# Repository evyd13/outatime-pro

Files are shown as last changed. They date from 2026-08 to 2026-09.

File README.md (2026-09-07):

# Outatime Pro
A PCB for Casio CA-53W or 3208 module based on the [Sensor Watch Pro](https://github.com/joeycastillo/Sensor-Watch). It has the same features!

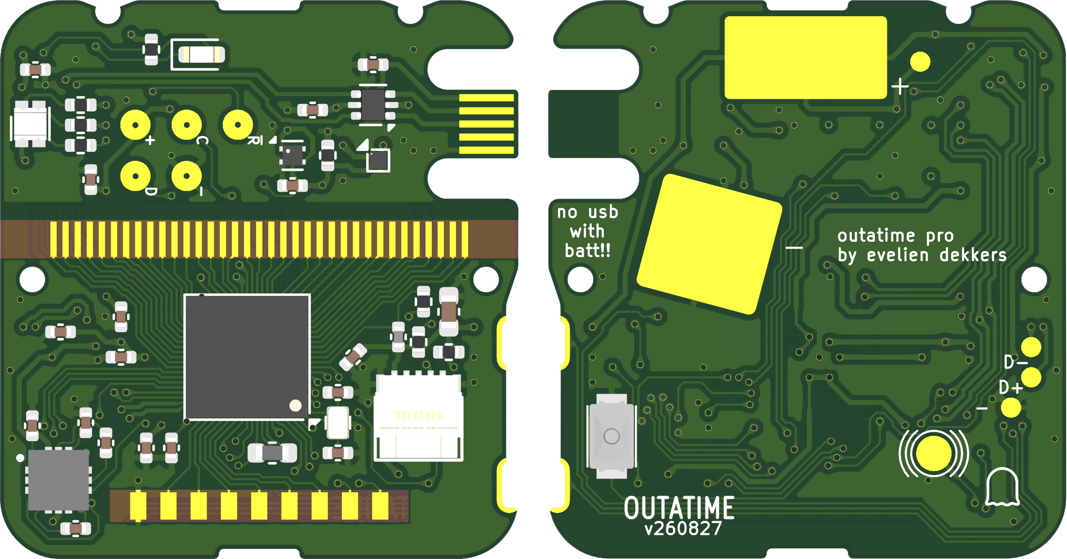
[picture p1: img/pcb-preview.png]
PCB view


# Firmware
Firmware is being worked on [here](https://github.com/evyd13/second-movement/tree/outatime-pro).

# WARNING
THIS IS NOT TESTED IN ANY WAY. DO NOT ORDER THIS THINKING IT WILL WORK. FIRMWARE DOESN'T EXIST FOR IT YET. IT IS A WORK IN PROGRESS.
However, the PCB design is done.

## Version number
Version number is date formate yyMMDD, August 25th 2026 would be v260825.

# To-Do
The following still needs work:

- Firmware needs to be finished (work has started!)
- figure out if the selection signals for PAM8904 need to be connected to GPIO or always HIGH.
- PCB needs to be ordered and tested (I intend to do this in a few months time, need to gather funds for a prototype)
- It needs to be worn and loved!!

# Bootloader
I contacted devolov, they said to me that the firmware needs to be flashed with utils/flash_watch_pyruler using Adafruit PyRuler or Trinket. (I intend to use Seeed XIAO or maybe Pi Pico.)

Bootloader.h is generated from https://github.com/joeycastillo/uf2-samdx1.
(Thanks @devolov!)

# LCD
The LCD is fairly simple. It has 35 pins, of which the leftmost is not connected. The first 3 connected pins are common, the rest are segments. Mapping can be found within the emulator svg file or watch_common_display.h. (Seg08 and seg01 are swapped in software to allow blinking)

# Thanks to and relevant projects
- Joey Castillo for Sensor Watch, which this project is mostly based on. https://github.com/joeycastillo/Sensor-Watch/tree/main
- Travis Goodspeed, for incredible documentation about the Casio CA-53W. https://github.com/travisgoodspeed/goodwatch
- Vasily Zhuravsky, for a nice USB edge connector library https://github.com/vasya-zh/PCB-Edge-USB-connector-KiCad-library
- Dmitry Teplitsky, for making me think I can do it https://github.com/icelord75/icesio
- Greg Davill, for pointing the way to a microcontroller to use. https://github.com/gregdavill/advent-calendar-of-circuits-2020/tree/main/arm-watch

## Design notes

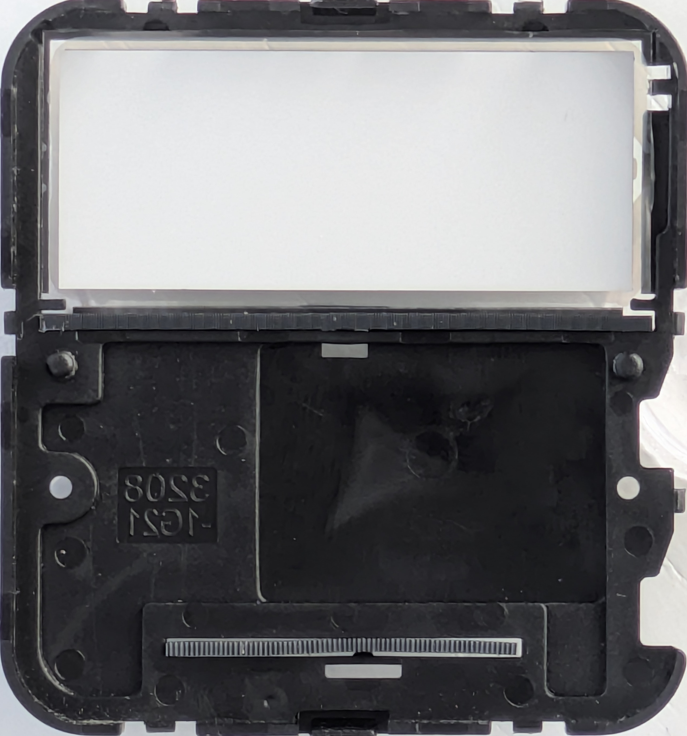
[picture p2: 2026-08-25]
PCB/ref/display cover.png

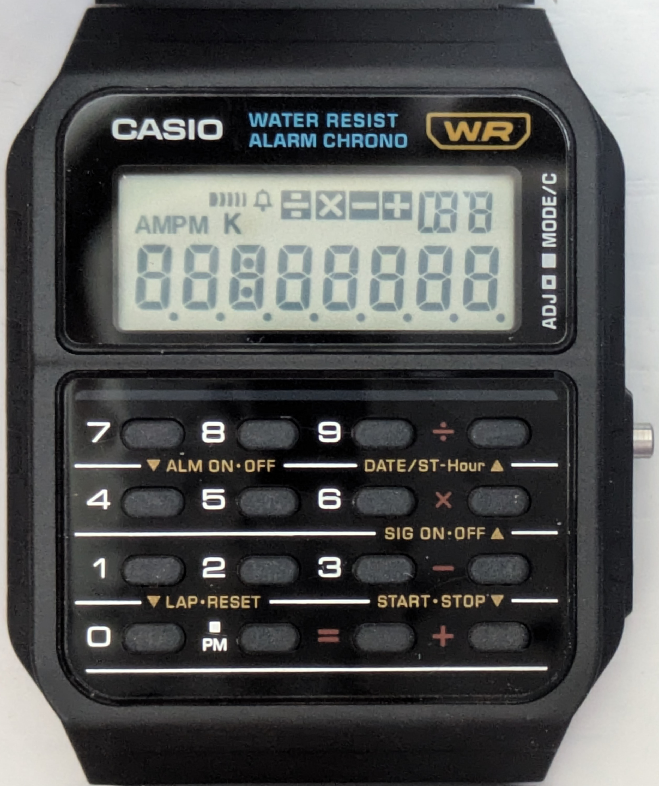
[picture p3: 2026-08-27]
PCB/ref/display.png

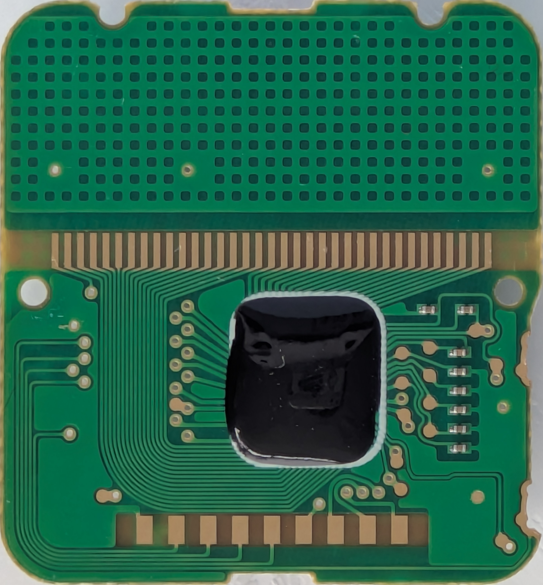
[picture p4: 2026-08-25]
PCB/ref/display side.png

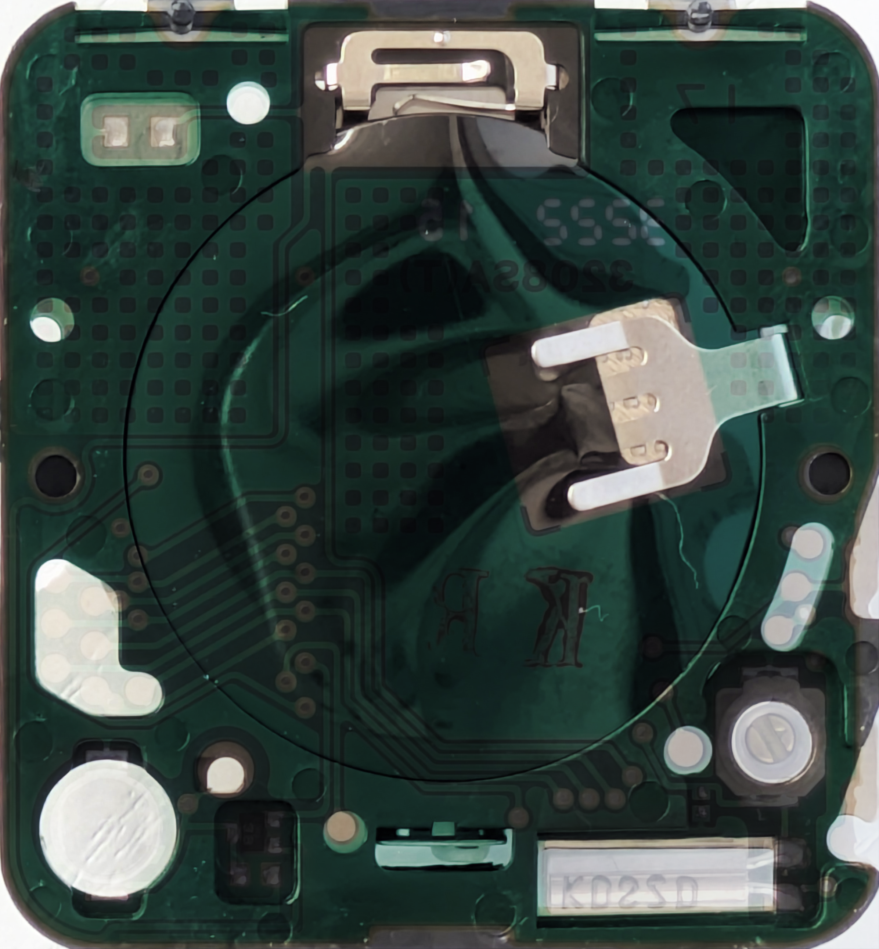
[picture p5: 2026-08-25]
PCB/ref/battery side w battery cover.png

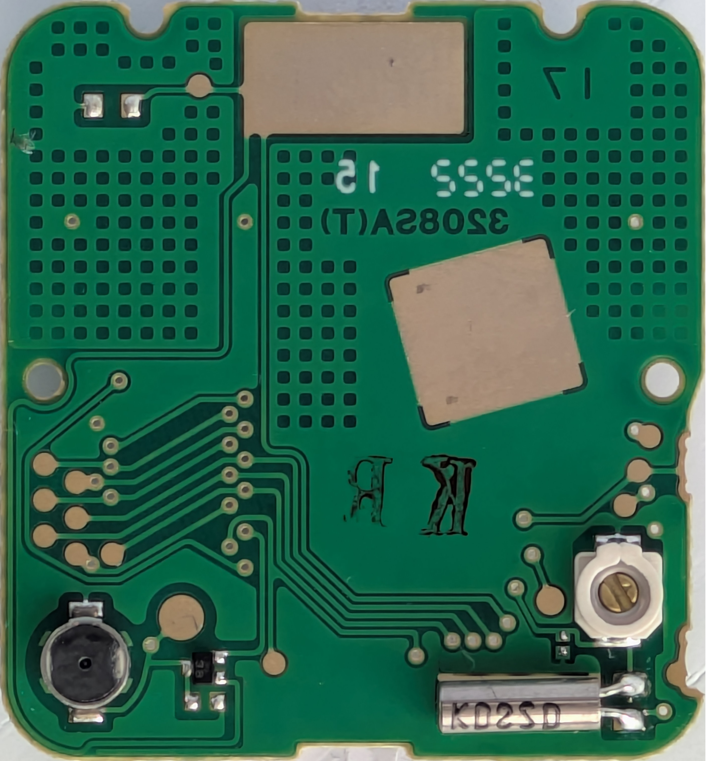
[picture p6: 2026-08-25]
PCB/ref/battery side.png

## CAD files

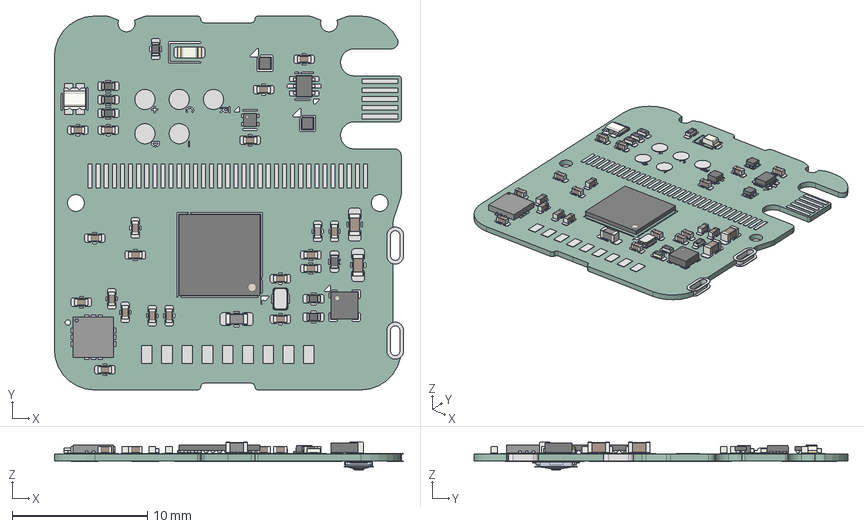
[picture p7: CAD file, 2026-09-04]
PCB/OutatimePro.step
25.9 x 27.7 x 2.04 mm
C_0402_1005Metric x 19
LED_0603_1608Metric v1
FC1610AN_PKG
UFBGA-100_6.0x6.0mm_Layout11x11_P0.5mm_Ball0.3mm_Pad0.25mm_NSMD v1
R_0402_1005Metric x 7
TH_0402_1005Metric v1
C_0603_1608Metric x 2
LGA-12_2x2mm_P0.5mm v1
WLP-4_0.83x0.83mm_P0.4mm x 2
SOT_666
PAM8904JPR v1
DFN_4_1EP_1x1mm_P065mm_EP05x05mm
L_0603_1608Metric
3Dmodel
OutatimePro_pad
OutatimePro_silkscreen x 2
OutatimePro_PCB

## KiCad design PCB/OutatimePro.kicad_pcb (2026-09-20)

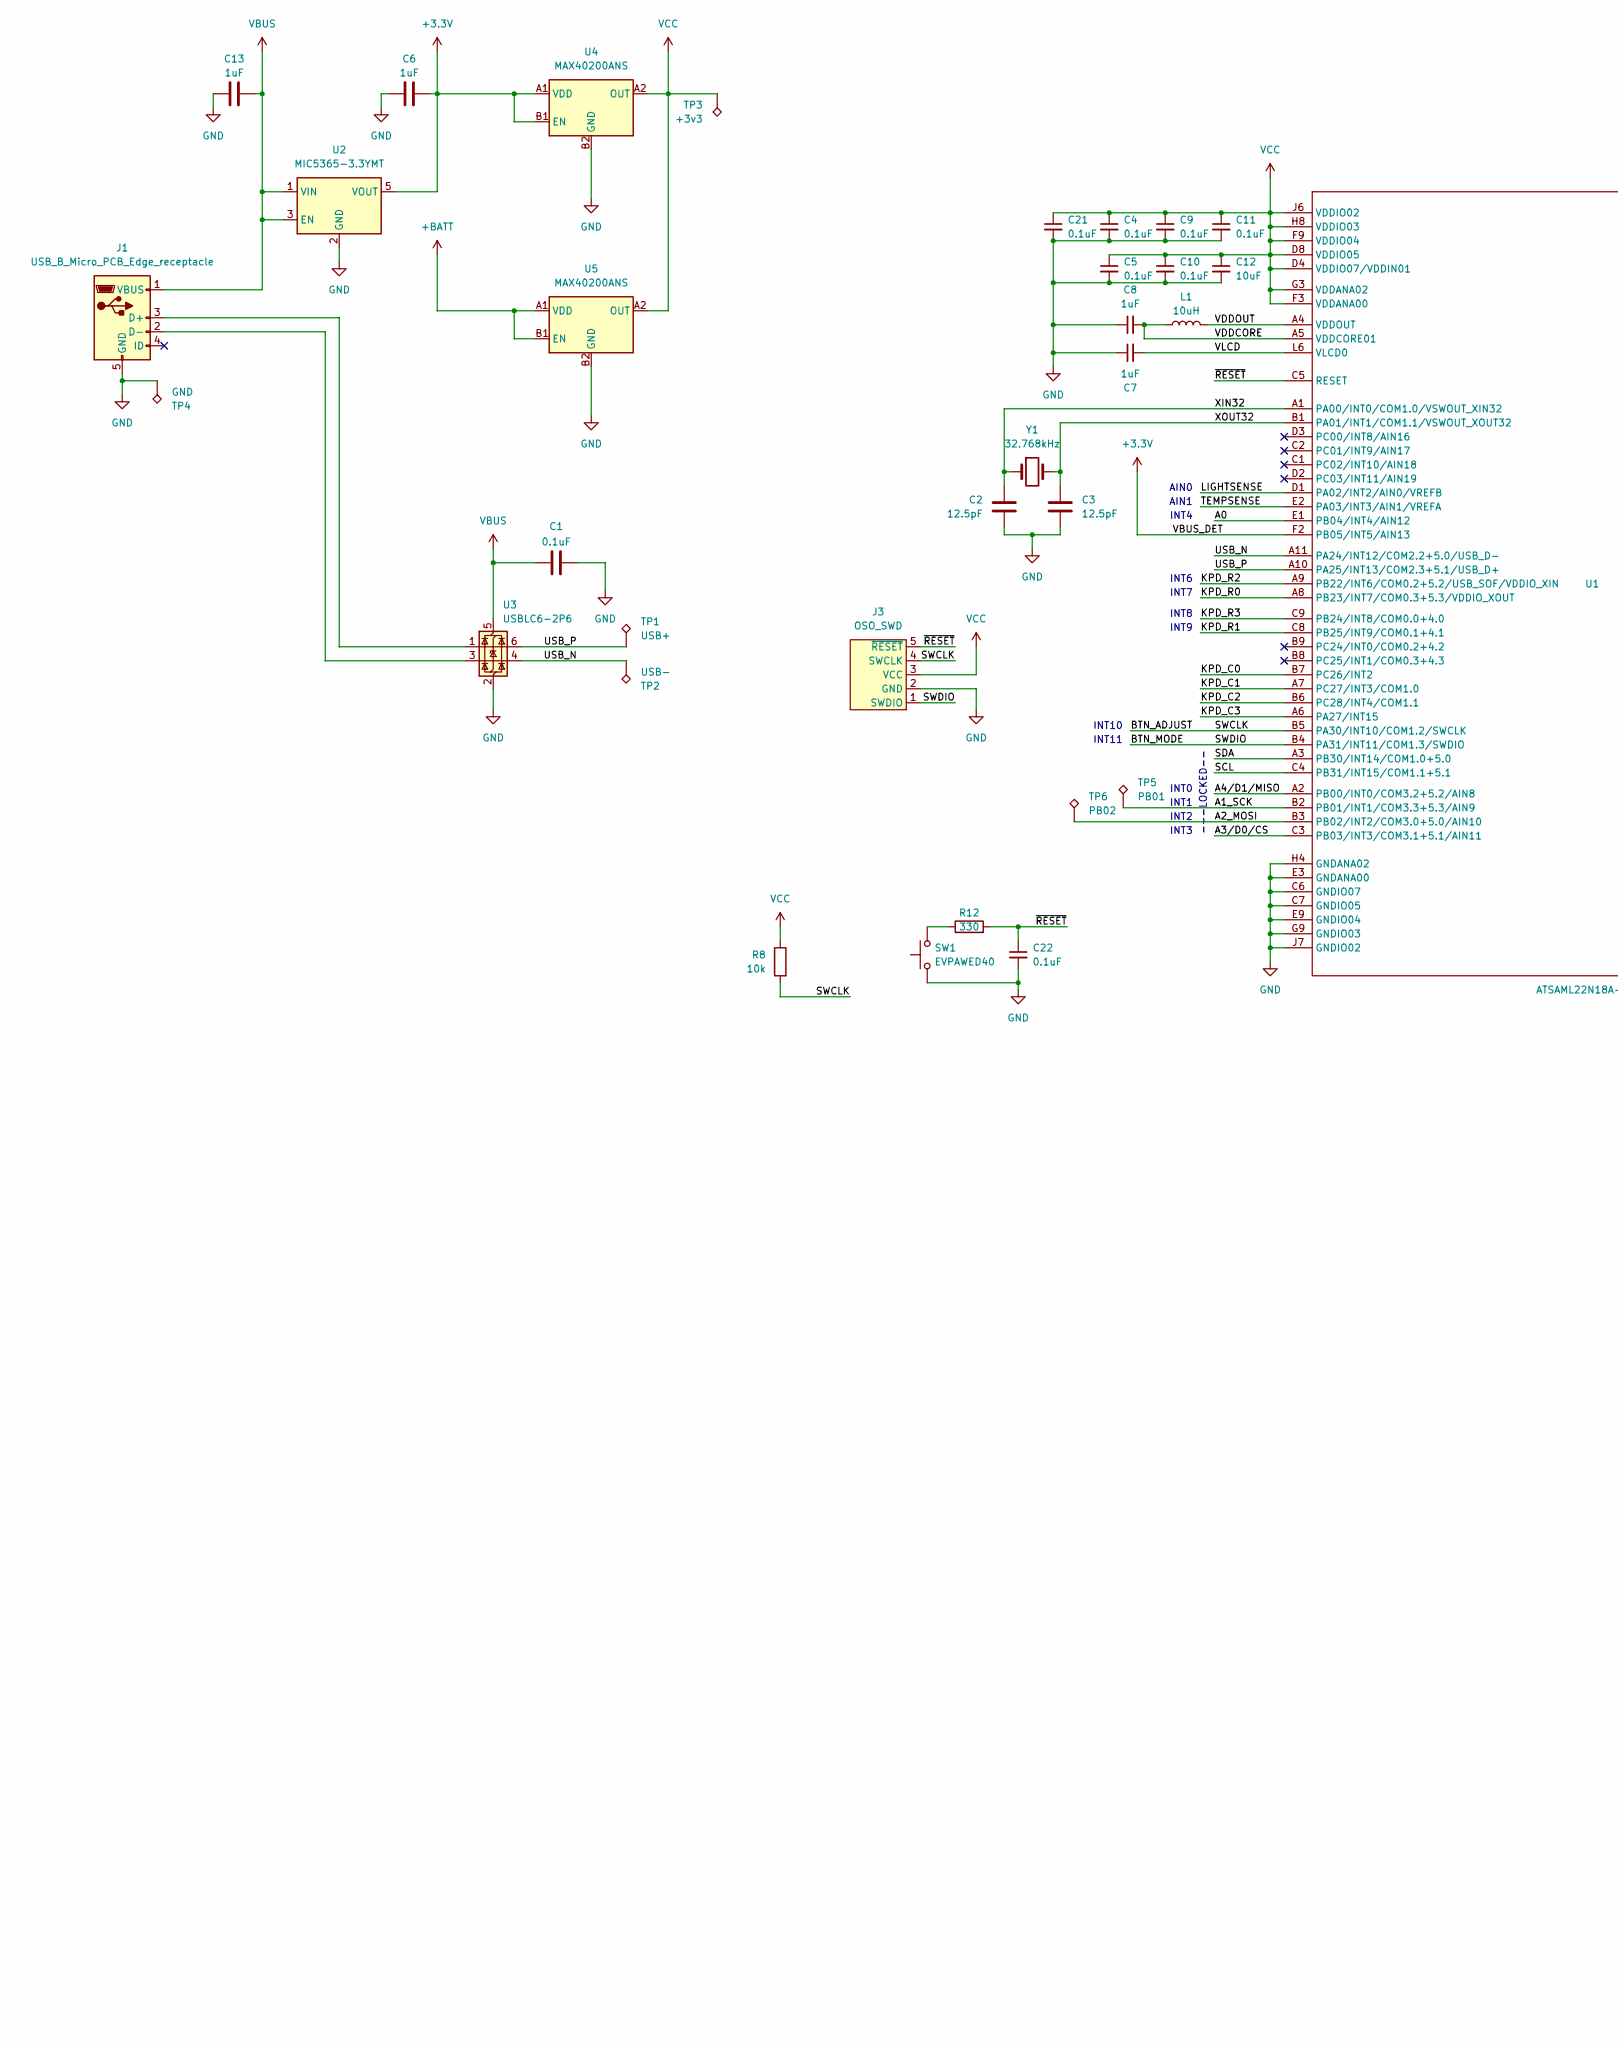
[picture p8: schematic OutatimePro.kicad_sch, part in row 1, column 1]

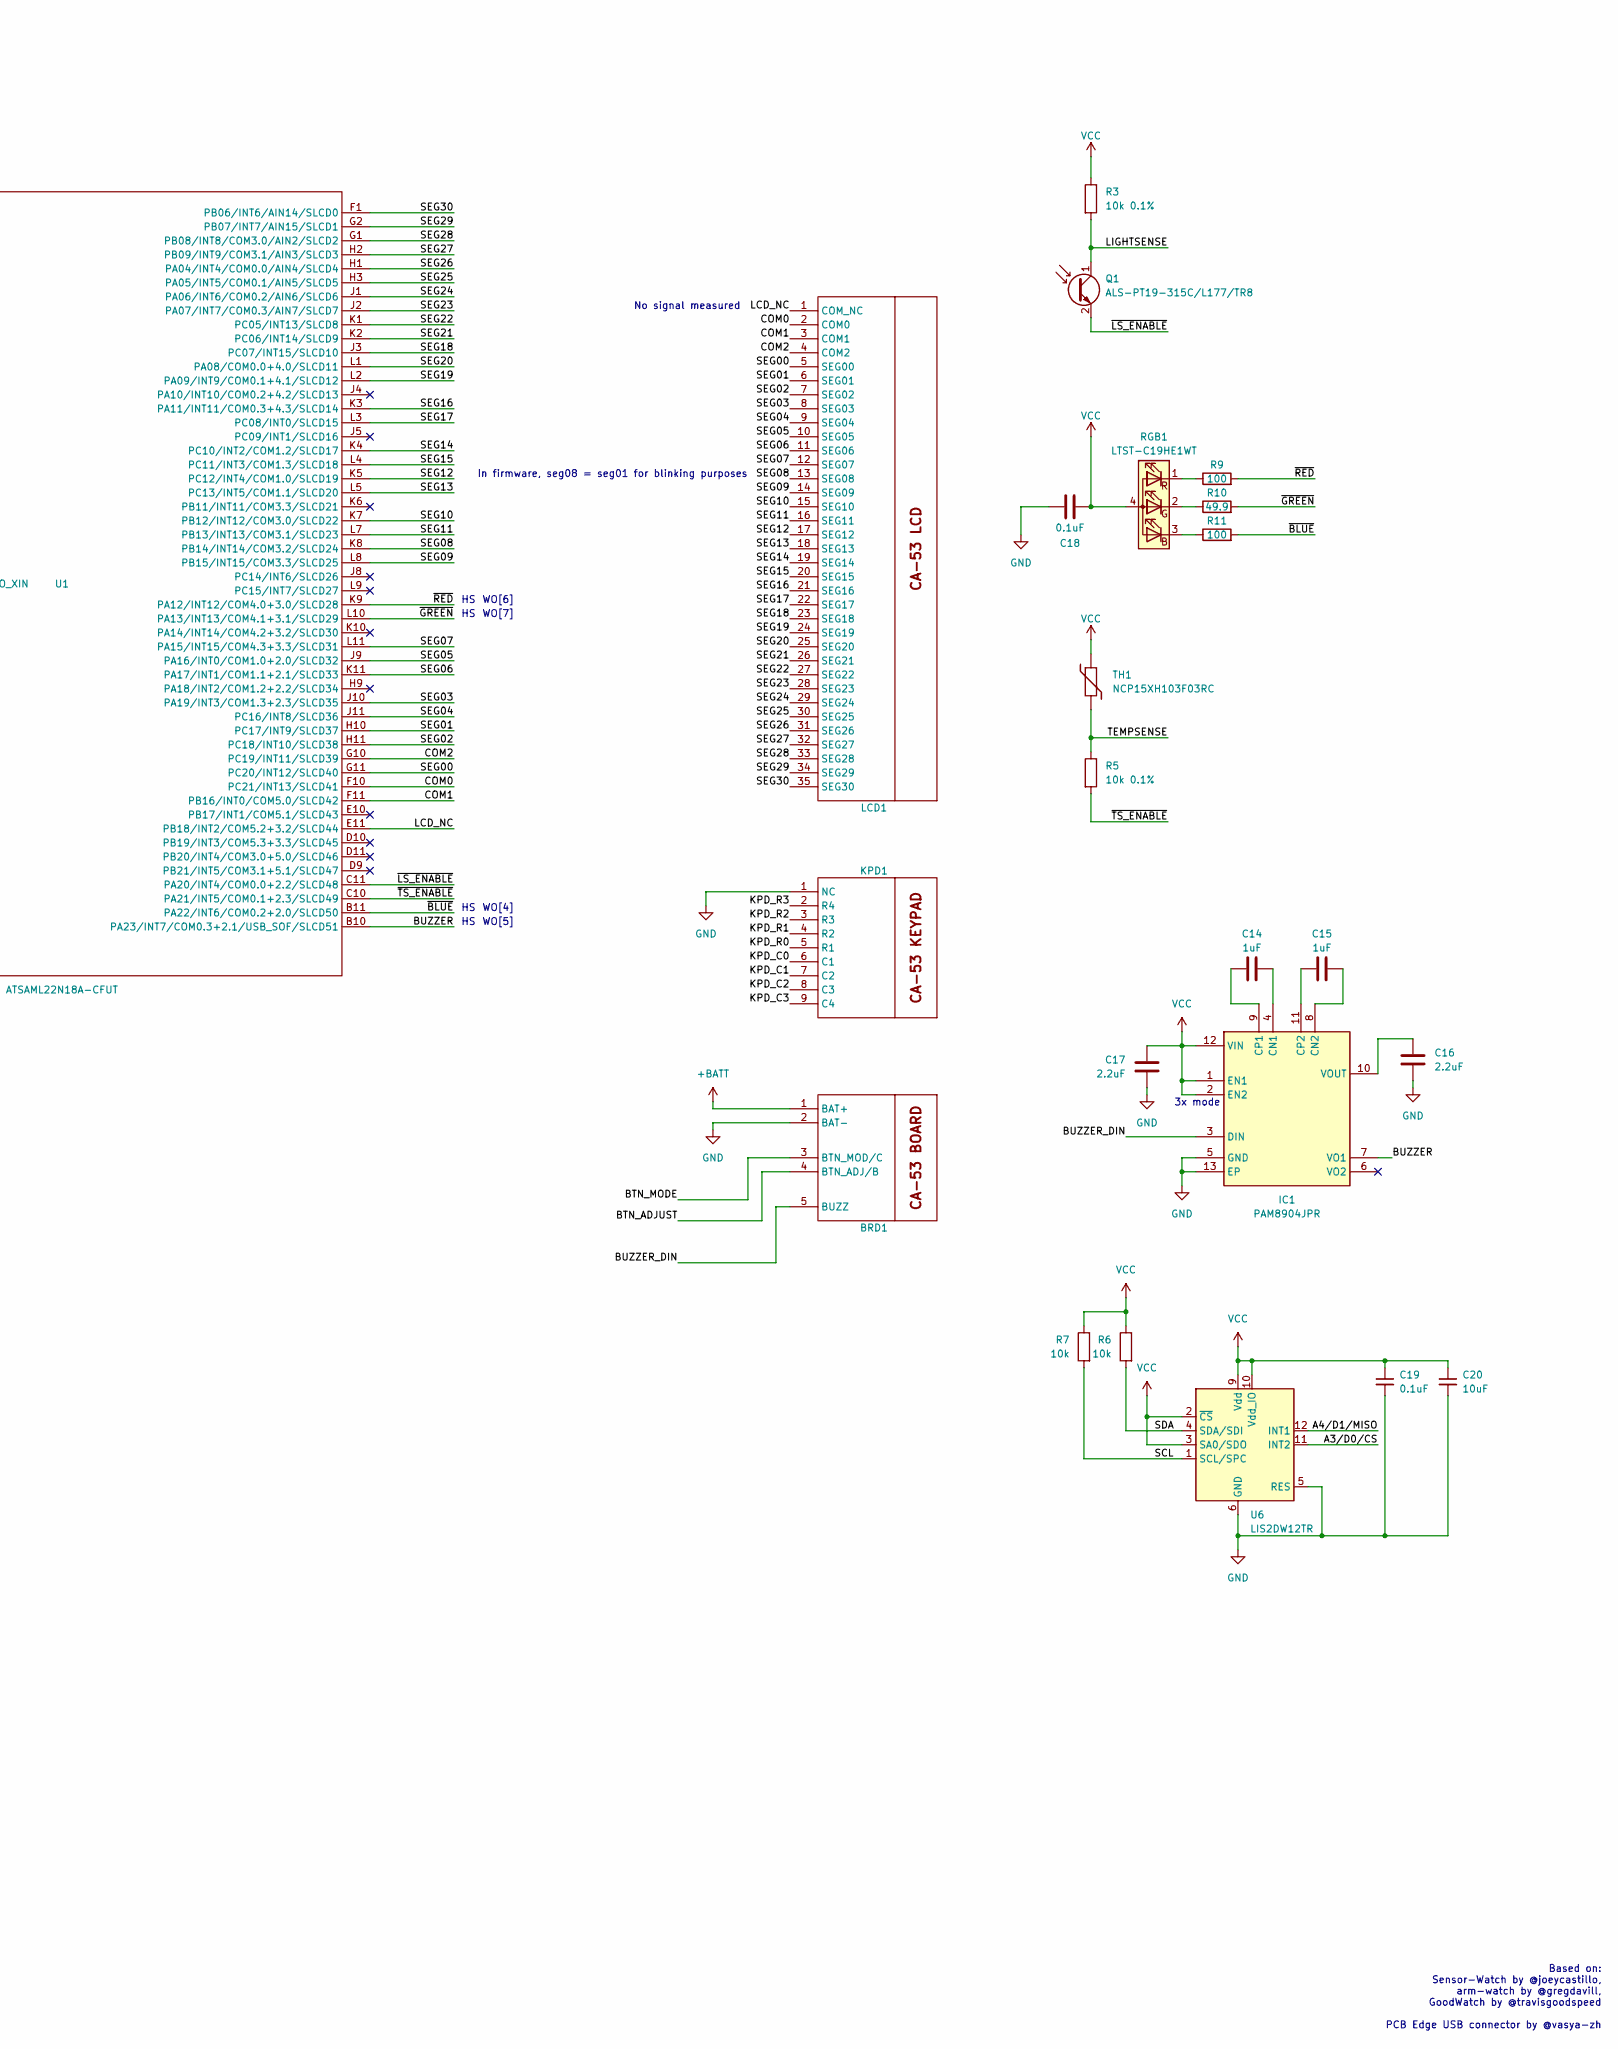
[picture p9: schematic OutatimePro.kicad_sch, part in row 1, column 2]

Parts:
BRD1: ca53board
C1, C4, C5, C9, C10, C11, C18, C19, C21, C22: 0.1uF; C_0402_1005Metric; LCSC Part # C14663
C2, C3: 12.5pF; C_0402_1005Metric; LCSC Part # C1547
C6, C7, C8, C13, C14, C15: 1uF; C_0402_1005Metric; LCSC Part # C52923
C12, C20: 10uF; C_0603_1608Metric; LCSC Part # C19702
C16, C17: 2.2uF; C_0402_1005Metric; LCSC Part # C12530
IC1: PAM8904JPR; LCSC Part # C780875
J1: USB_B_Micro_PCB_Edge_receptacle; USB_Micro-B_PCB_receptacle_5pin_2mm_cutout
J3: OSO_SWD; OSO_SWD_2x3
KPD1: ca53keypad
L1: 10uH; L_0603_1608Metric; LCSC Part # C1035
LCD1: ca53lcd
Q1: ALS-PT19-315C/L177/TR8; ALS-PT19-315C; LCSC Part # C146233
R3, R5: 10k 0.1%; R_0402_1005Metric; LCSC Part # C517449
R6, R7, R8: 10k; R_0402_1005Metric; LCSC Part # C25744
R9, R11: 100; R_0402_1005Metric; LCSC Part # C25076
R10: 49.9; R_0402_1005Metric; LCSC Part # C25120
R12: 330; R_0402_1005Metric; LCSC Part # C25104
RGB1: LTST-C19HE1WT; LED_LiteOn_LTST-C19HE1WT; LCSC Part # C458749
SW1: EVPAWED40; Panasonic_EVPAW_EVP6A; LCSC Part # C2858607
TH1: NCP15XH103F03RC; TH_0402_1005Metric; LCSC Part # C77131
TP1: USB+; TestPoint_Pad_D1.0mm
TP2: USB-; TestPoint_Pad_D1.0mm
TP3: +3v3; TestPoint_Pad_D1.0mm
TP4: GND; TestPoint_Pad_D1.0mm
TP5: PB01; TestPoint_Pad_D1.0mm
TP6: PB02; TestPoint_Pad_D1.0mm
U1: ATSAML22N18A-CFUT; UFBGA-100_6.0x6.0mm_Layout11x11_P0.5mm_Ball0.3mm_Pad0.25mm_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; LCSC Part # C2055605
U2: MIC5365-3.3YMT; UDFN-4-1EP_1x1mm_P0.65mm_EP0.48x0.48mm; LCSC Part # C512103
U3: USBLC6-2P6; SOT-666; LCSC Part # C15999
U4, U5: MAX40200ANS; WLP-4_0.728x0.728mm_Layout2x2_P0.35mm; LCSC Part # C3227637
U6: LIS2DW12TR; LGA-12_2x2mm_P0.5mm; LCSC Part # C189624
Y1: 32.768kHz; Crystal_SMD_1610-2Pin_1.6x1.0mm; LCSC Part # C5154201

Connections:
+3.3V: C6.2, U1.F2 (PB05/INT5/AIN13), U2.5 (VOUT), U4.A1 (VDD), U4.B1 (EN)
+BATT: BRD1.1 (BAT+), U5.A1 (VDD), U5.B1 (EN)
/A0: U1.E1 (PB04/INT4/AIN12)
/A1_SCK: TP5.1 (1_1), U1.B2 (PB01/INT1/COM3.3+5.3/AIN9)
/A2_MOSI: TP6.1 (1_1), U1.B3 (PB02/INT2/COM3.0+5.0/AIN10)
/A3/D0/CS: U1.C3 (PB03/INT3/COM3.1+5.1/AIN11), U6.11 (INT2)
/A4/D1/MISO: U1.A2 (PB00/INT0/COM3.2+5.2/AIN8), U6.12 (INT1)
/BTN_ADJUST: BRD1.4 (BTN_ADJ/B), J3.4 (SWCLK), R8.2, U1.B5 (PA30/INT10/COM1.2/SWCLK)
/BTN_MODE: BRD1.3 (BTN_MOD/C), J3.1 (SWDIO), U1.B4 (PA31/INT11/COM1.3/SWDIO)
/BUZZER: IC1.7 (VO1), U1.B10 (PA23/INT7/COM0.3+2.1/USB_SOF/SLCD51)
/BUZZER_DIN: BRD1.5 (BUZZ), IC1.3 (DIN)
/COM0: LCD1.2 (COM0), U1.F10 (PC21/INT13/SLCD41)
/COM1: LCD1.3 (COM1), U1.F11 (PB16/INT0/COM5.0/SLCD42)
/COM2: LCD1.4 (COM2), U1.G10 (PC19/INT11/SLCD39)
/KPD_C0: KPD1.6 (C1), U1.B7 (PC26/INT2)
/KPD_C1: KPD1.7 (C2), U1.A7 (PC27/INT3/COM1.0)
/KPD_C2: KPD1.8 (C3), U1.B6 (PC28/INT4/COM1.1)
/KPD_C3: KPD1.9 (C4), U1.A6 (PA27/INT15)
/KPD_R0: KPD1.5 (R1), U1.A8 (PB23/INT7/COM0.3+5.3/VDDIO_XOUT)
/KPD_R1: KPD1.4 (R2), U1.C8 (PB25/INT9/COM0.1+4.1)
/KPD_R2: KPD1.3 (R3), U1.A9 (PB22/INT6/COM0.2+5.2/USB_SOF/VDDIO_XIN)
/KPD_R3: KPD1.2 (R4), U1.C9 (PB24/INT8/COM0.0+4.0)
/LCD_NC: LCD1.1 (COM_NC), U1.E11 (PB18/INT2/COM5.2+3.2/SLCD44)
/LIGHTSENSE: Q1.1 (C), R3.2, U1.D1 (PA02/INT2/AIN0/VREFB)
/SCL: R7.2, U1.C4 (PB31/INT15/COM1.1+5.1), U6.1 (SCL/SPC)
/SDA: R6.2, U1.A3 (PB30/INT14/COM1.0+5.0), U6.4 (SDA/SDI)
/SEG00: LCD1.5 (SEG00), U1.G11 (PC20/INT12/SLCD40)
/SEG01: LCD1.6 (SEG01), U1.H10 (PC17/INT9/SLCD37)
/SEG02: LCD1.7 (SEG02), U1.H11 (PC18/INT10/SLCD38)
/SEG03: LCD1.8 (SEG03), U1.J10 (PA19/INT3/COM1.3+2.3/SLCD35)
/SEG04: LCD1.9 (SEG04), U1.J11 (PC16/INT8/SLCD36)
/SEG05: LCD1.10 (SEG05), U1.J9 (PA16/INT0/COM1.0+2.0/SLCD32)
/SEG06: LCD1.11 (SEG06), U1.K11 (PA17/INT1/COM1.1+2.1/SLCD33)
/SEG07: LCD1.12 (SEG07), U1.L11 (PA15/INT15/COM4.3+3.3/SLCD31)
/SEG08: LCD1.13 (SEG08), U1.K8 (PB14/INT14/COM3.2/SLCD24)
/SEG09: LCD1.14 (SEG09), U1.L8 (PB15/INT15/COM3.3/SLCD25)
/SEG10: LCD1.15 (SEG10), U1.K7 (PB12/INT12/COM3.0/SLCD22)
/SEG11: LCD1.16 (SEG11), U1.L7 (PB13/INT13/COM3.1/SLCD23)
/SEG12: LCD1.17 (SEG12), U1.K5 (PC12/INT4/COM1.0/SLCD19)
/SEG13: LCD1.18 (SEG13), U1.L5 (PC13/INT5/COM1.1/SLCD20)
/SEG14: LCD1.19 (SEG14), U1.K4 (PC10/INT2/COM1.2/SLCD17)
/SEG15: LCD1.20 (SEG15), U1.L4 (PC11/INT3/COM1.3/SLCD18)
/SEG16: LCD1.21 (SEG16), U1.K3 (PA11/INT11/COM0.3+4.3/SLCD14)
/SEG17: LCD1.22 (SEG17), U1.L3 (PC08/INT0/SLCD15)
/SEG18: LCD1.23 (SEG18), U1.J3 (PC07/INT15/SLCD10)
/SEG19: LCD1.24 (SEG19), U1.L2 (PA09/INT9/COM0.1+4.1/SLCD12)
/SEG20: LCD1.25 (SEG20), U1.L1 (PA08/COM0.0+4.0/SLCD11)
/SEG21: LCD1.26 (SEG21), U1.K2 (PC06/INT14/SLCD9)
/SEG22: LCD1.27 (SEG22), U1.K1 (PC05/INT13/SLCD8)
/SEG23: LCD1.28 (SEG23), U1.J2 (PA07/INT7/COM0.3/AIN7/SLCD7)
/SEG24: LCD1.29 (SEG24), U1.J1 (PA06/INT6/COM0.2/AIN6/SLCD6)
/SEG25: LCD1.30 (SEG25), U1.H3 (PA05/INT5/COM0.1/AIN5/SLCD5)
/SEG26: LCD1.31 (SEG26), U1.H1 (PA04/INT4/COM0.0/AIN4/SLCD4)
/SEG27: LCD1.32 (SEG27), U1.H2 (PB09/INT9/COM3.1/AIN3/SLCD3)
/SEG28: LCD1.33 (SEG28), U1.G1 (PB08/INT8/COM3.0/AIN2/SLCD2)
/SEG29: LCD1.34 (SEG29), U1.G2 (PB07/INT7/AIN15/SLCD1)
/SEG30: LCD1.35 (SEG30), U1.F1 (PB06/INT6/AIN14/SLCD0)
/TEMPSENSE: R5.1, TH1.2, U1.E2 (PA03/INT3/AIN1/VREFA)
/USB_N: TP2.1 (1_1), U1.A11 (PA24/INT12/COM2.2+5.0/USB_D-), U3.4 (I/O2)
/USB_P: TP1.1 (1_1), U1.A10 (PA25/INT13/COM2.3+5.1/USB_D+), U3.6 (I/O1)
/VDDCORE: C8.2, L1.1, U1.A5 (VDDCORE01)
/VDDOUT: L1.2, U1.A4 (VDDOUT)
/VLCD: C7.2, U1.L6 (VLCD0)
/XIN32: C2.1, U1.A1 (PA00/INT0/COM1.0/VSWOUT_XIN32), Y1.1
/XOUT32: C3.1, U1.B1 (PA01/INT1/COM1.1/VSWOUT_XOUT32), Y1.2
/~BLUE: R11.2, U1.B11 (PA22/INT6/COM0.2+2.0/SLCD50)
/~GREEN: R10.2, U1.L10 (PA13/INT13/COM4.1+3.1/SLCD29)
/~LS_ENABLE: Q1.2 (E), U1.C11 (PA20/INT4/COM0.0+2.2/SLCD48)
/~RED: R9.2, U1.K9 (PA12/INT12/COM4.0+3.0/SLCD28)
/~RESET: C22.1, J3.5 (~RESET), R12.2, U1.C5 (RESET)
/~TS_ENABLE: R5.2, U1.C10 (PA21/INT5/COM0.1+2.3/SLCD49)
GND: BRD1.2 (BAT-), C1.2, C2.2, C3.2, C4.2, C5.2, C6.1, C7.1, C8.1, C9.2, C10.2, C11.2, C12.2, C13.1, C16.1, C17.1, C18.1, C19.2, C20.2, C21.2, C22.2, IC1.5 (GND), IC1.13 (EP), J1.5 (GND), J3.2 (GND), KPD1.1 (NC), SW1.1, TP4.1 (1_1), U1.C6 (GNDIO07), U1.C7 (GNDIO05), U1.E3 (GNDANA00), U1.E9 (GNDIO04), U1.G9 (GNDIO03), U1.H4 (GNDANA02), U1.J7 (GNDIO02), U2.2 (GND), U3.2 (GND), U4.B2 (GND), U5.B2 (GND), U6.5 (RES), U6.6 (GND), U6.7 (GND), U6.8 (GND)
unnamed: C14.2, IC1.4 (CN1)
unnamed: C15.2, IC1.8 (CN2)
unnamed: C14.1, IC1.9 (CP1)
unnamed: C15.1, IC1.11 (CP2)
unnamed: C16.2, IC1.10 (VOUT)
unnamed: J1.3 (D+), U3.1 (I/O1)
unnamed: J1.2 (D-), U3.3 (I/O2)
unnamed: R12.1, SW1.2
unnamed: R11.1, RGB1.3 (BK)
unnamed: R10.1, RGB1.2 (GK)
unnamed: R9.1, RGB1.1 (RK)
VBUS: C1.1, C13.2, J1.1 (VBUS), U2.1 (VIN), U2.3 (EN), U3.5 (VBUS)
VCC: C4.1, C5.1, C9.1, C10.1, C11.1, C12.1, C17.2, C18.2, C19.1, C20.1, C21.1, IC1.1 (EN1), IC1.2 (EN2), IC1.12 (VIN), J3.3 (VCC), R3.1, R6.1, R7.1, R8.1, RGB1.4 (A), TH1.1, TP3.1 (1_1), U1.D4 (VDDIO07/VDDIN01), U1.D8 (VDDIO05), U1.F3 (VDDANA00), U1.F9 (VDDIO04), U1.G3 (VDDANA02), U1.H8 (VDDIO03), U1.J6 (VDDIO02), U4.A2 (OUT), U5.A2 (OUT), U6.2 (~CS), U6.3 (SA0/SDO), U6.9 (Vdd), U6.10 (Vdd_IO)

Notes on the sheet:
INT0
INT2
WO[6]
WO[4]
INT1
INT8
INT11
INT10
WO[7]
INT3
---LOCKED--
INT7
INT9
3x mode
No signal measured
INT4
AIN0
WO[5]
Based on: Sensor-Watch by @joeycastillo, arm-watch by @gregdavill, GoodWatch by @travisgoodspeed PCB Edge USB connector by @vasya-zh
INT6
AIN1
In firmware, seg08 = seg01 for blinking purposes

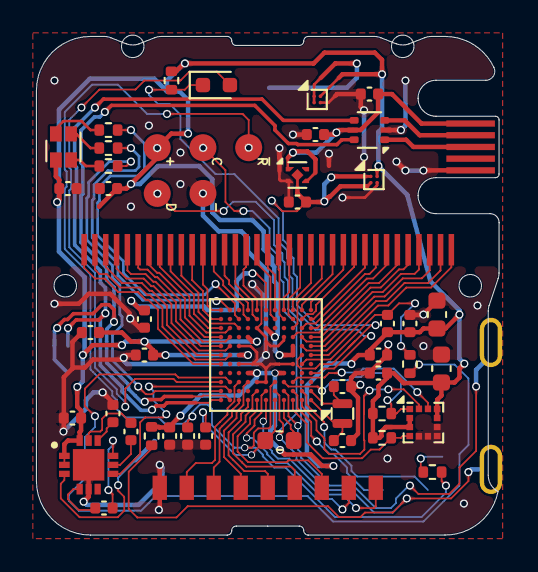
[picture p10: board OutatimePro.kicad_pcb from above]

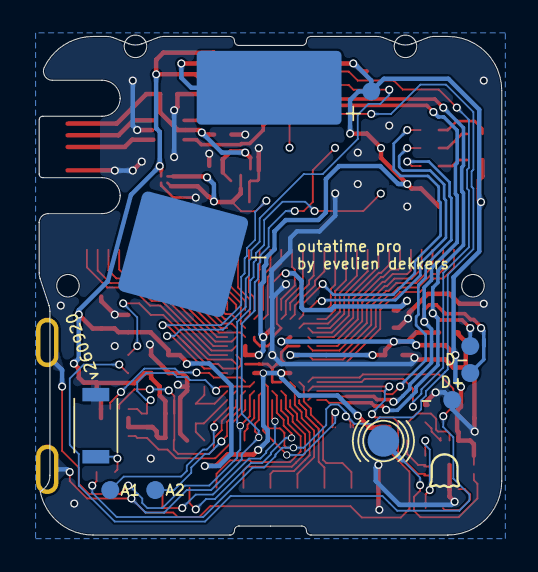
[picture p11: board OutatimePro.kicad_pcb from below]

Board: 2 copper layers, 25.7 x 27.7 mm, 55 parts (7 on the bottom side), 84 nets.

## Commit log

2026-08-25 Add PCBs v250826
    [OutatimePro.kicad_pcb, OutatimePro.kicad_sch, OutatimePro.step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]
2026-08-25 Add display clearance height
    [OutatimePro.kicad_pcb]
2026-08-26 add display clearance text to footprint
    [OutatimePro.kicad_pcb]
2026-08-27 v270826: change programming header, add test points
    [OutatimePro.kicad_pcb, OutatimePro.kicad_sch, OutatimeProAccelerometer.kicad_pcb]
2026-08-27 Add lcd mapping test pcb
    [CA53W_LCD_mapping.kicad_pcb, CA53W_LCD_mapping.kicad_sch, OutatimePro.kicad_pcb]
2026-08-27 move test pads to a good location
    [OutatimePro.kicad_pcb, OutatimePro.kicad_sch, OutatimePro.step]
2026-08-27 move test pads more and change version format
    [OutatimePro.kicad_pcb, OutatimePro.kicad_sch, OutatimePro.step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]
2026-08-27 resolve some drc errors, add cap to rgb led
    [OutatimePro.kicad_pcb, OutatimePro.kicad_sch, OutatimePro.step]
2026-08-27 make text consistent with programming header near test pad
    [OutatimePro.kicad_pcb]
2026-08-28 add pcb view in readme
2026-08-28 add nc makers to schematic
    [OutatimePro.kicad_pcb, OutatimePro.kicad_sch]
2026-08-28 rename kicad nets to row/columns t2b,l2r
    [OutatimePro.kicad_pcb, OutatimePro.kicad_sch]
2026-08-28 change keypad symbol pin names too
    [OutatimePro.kicad_pcb, OutatimePro.kicad_sch]
2026-08-29 Change keypad/button pins for available interrupts
    [OutatimePro.kicad_pcb, OutatimePro.kicad_sch]
2026-09-02 rename seg/com numbers to reflect firmware, fix up batt/vcc change circuitry
    [OutatimePro.kicad_pcb, OutatimePro.kicad_sch, OutatimeProAccelerometer.kicad_pcb]
2026-09-04 remove lcd mapping pcb and add lcsc component numbers to fpc board
    [CA53W_LCD_mapping.kicad_pcb, CA53W_LCD_mapping.kicad_sch, OutatimePro.kicad_pcb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]
2026-09-04 Remove FPC connector, put IMU on main pcb
    [OutatimePro.kicad_pcb, OutatimePro.kicad_sch, OutatimePro.step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]
2026-09-07 Add test points to break out A1/A2
    [OutatimePro.kicad_pcb, OutatimePro.kicad_sch]
2026-09-07 Rename Main PCB to PCB
    [OutatimePro.kicad_pcb, OutatimePro.kicad_sch, OutatimePro.step]
2026-09-19 move mcu to part where it fits & add promotional artwork
    [OutatimePro.kicad_pcb, OutatimePro.kicad_sch]
2026-09-20 add critical components for reliable operation (datasheet sch. checklist)
    [OutatimePro.kicad_pcb, OutatimePro.kicad_sch]
2026-10-16 Change programming header text size, change button pad copper size
2026-11-05 Tidy up footprints, correct LCSC parts and tidy up schematics
2026-11-06 Change bga pad size to 0.2mm, center castellated hole on edge cut, minor fixes
2026-11-07 Update led footprint pin 1 identification
